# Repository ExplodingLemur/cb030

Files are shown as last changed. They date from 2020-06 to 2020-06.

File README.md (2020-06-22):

# cb030
4-layer redesign of the [CB030](https://www.retrobrewcomputers.org/doku.php?id=builderpages:plasmo:cb030) homebrew computer by plasmo on retrobrewcomputers.org.

Specifically based on the [16-bit CF interface variant rev1](https://www.retrobrewcomputers.org/doku.php?id=builderpages:plasmo:cb030:cb030_rev1:16-bit_cf_upgrade)

Requires [these KiCAD library files](https://github.com/ExplodingLemur/kicad_libs)

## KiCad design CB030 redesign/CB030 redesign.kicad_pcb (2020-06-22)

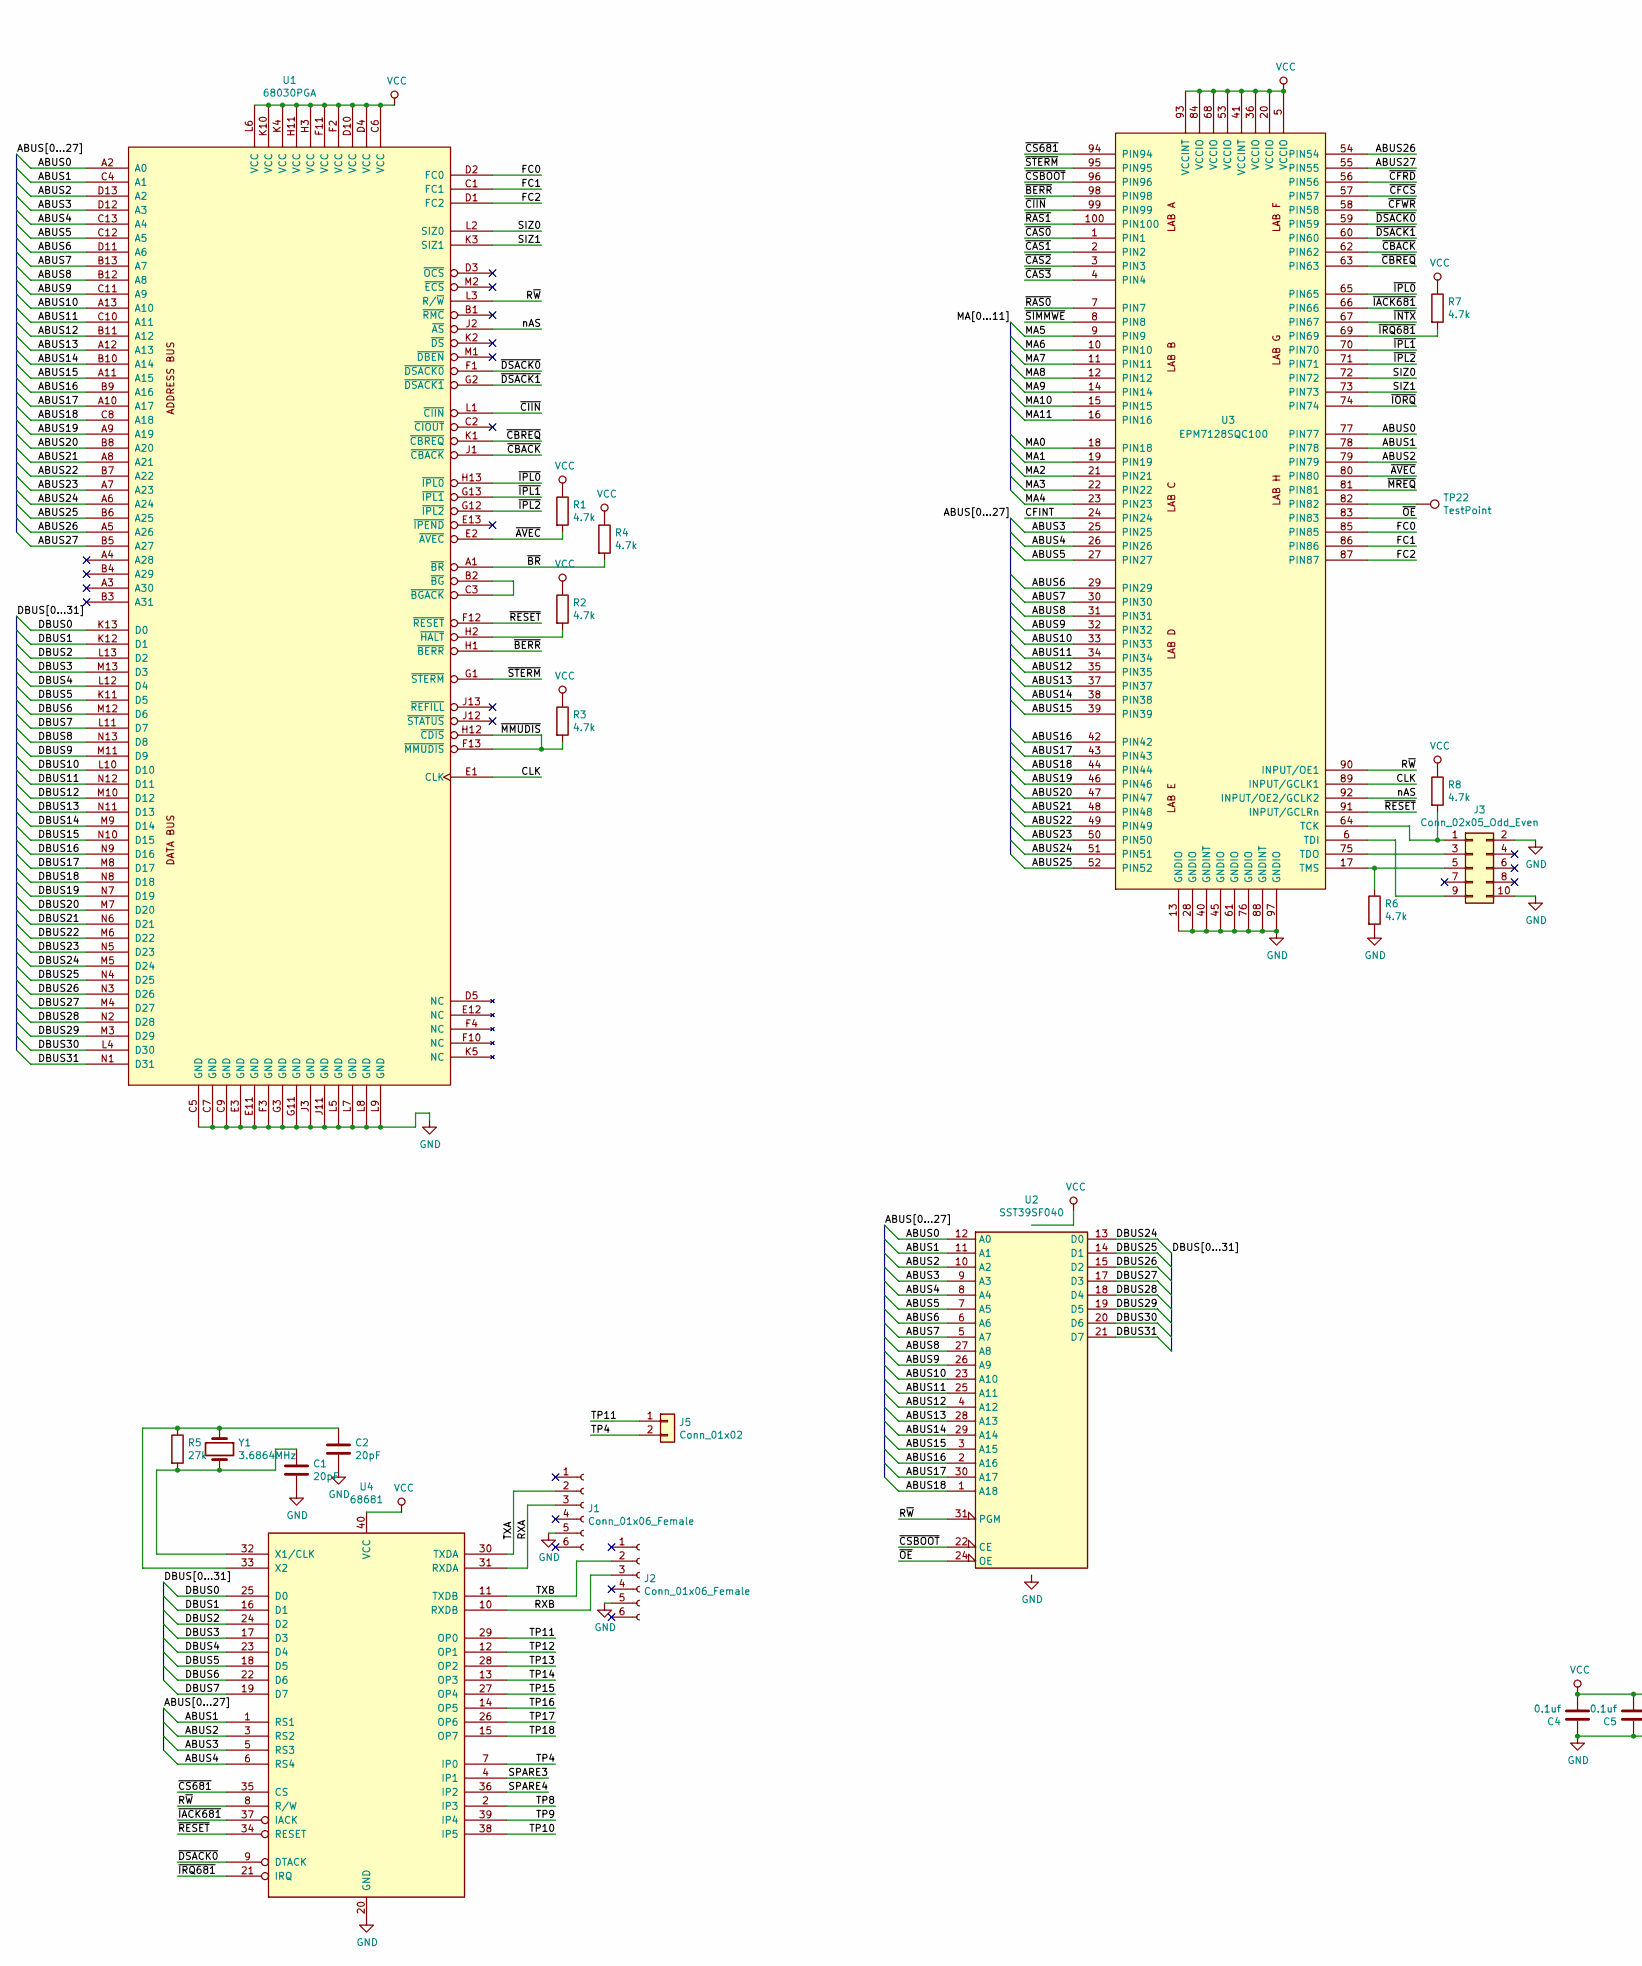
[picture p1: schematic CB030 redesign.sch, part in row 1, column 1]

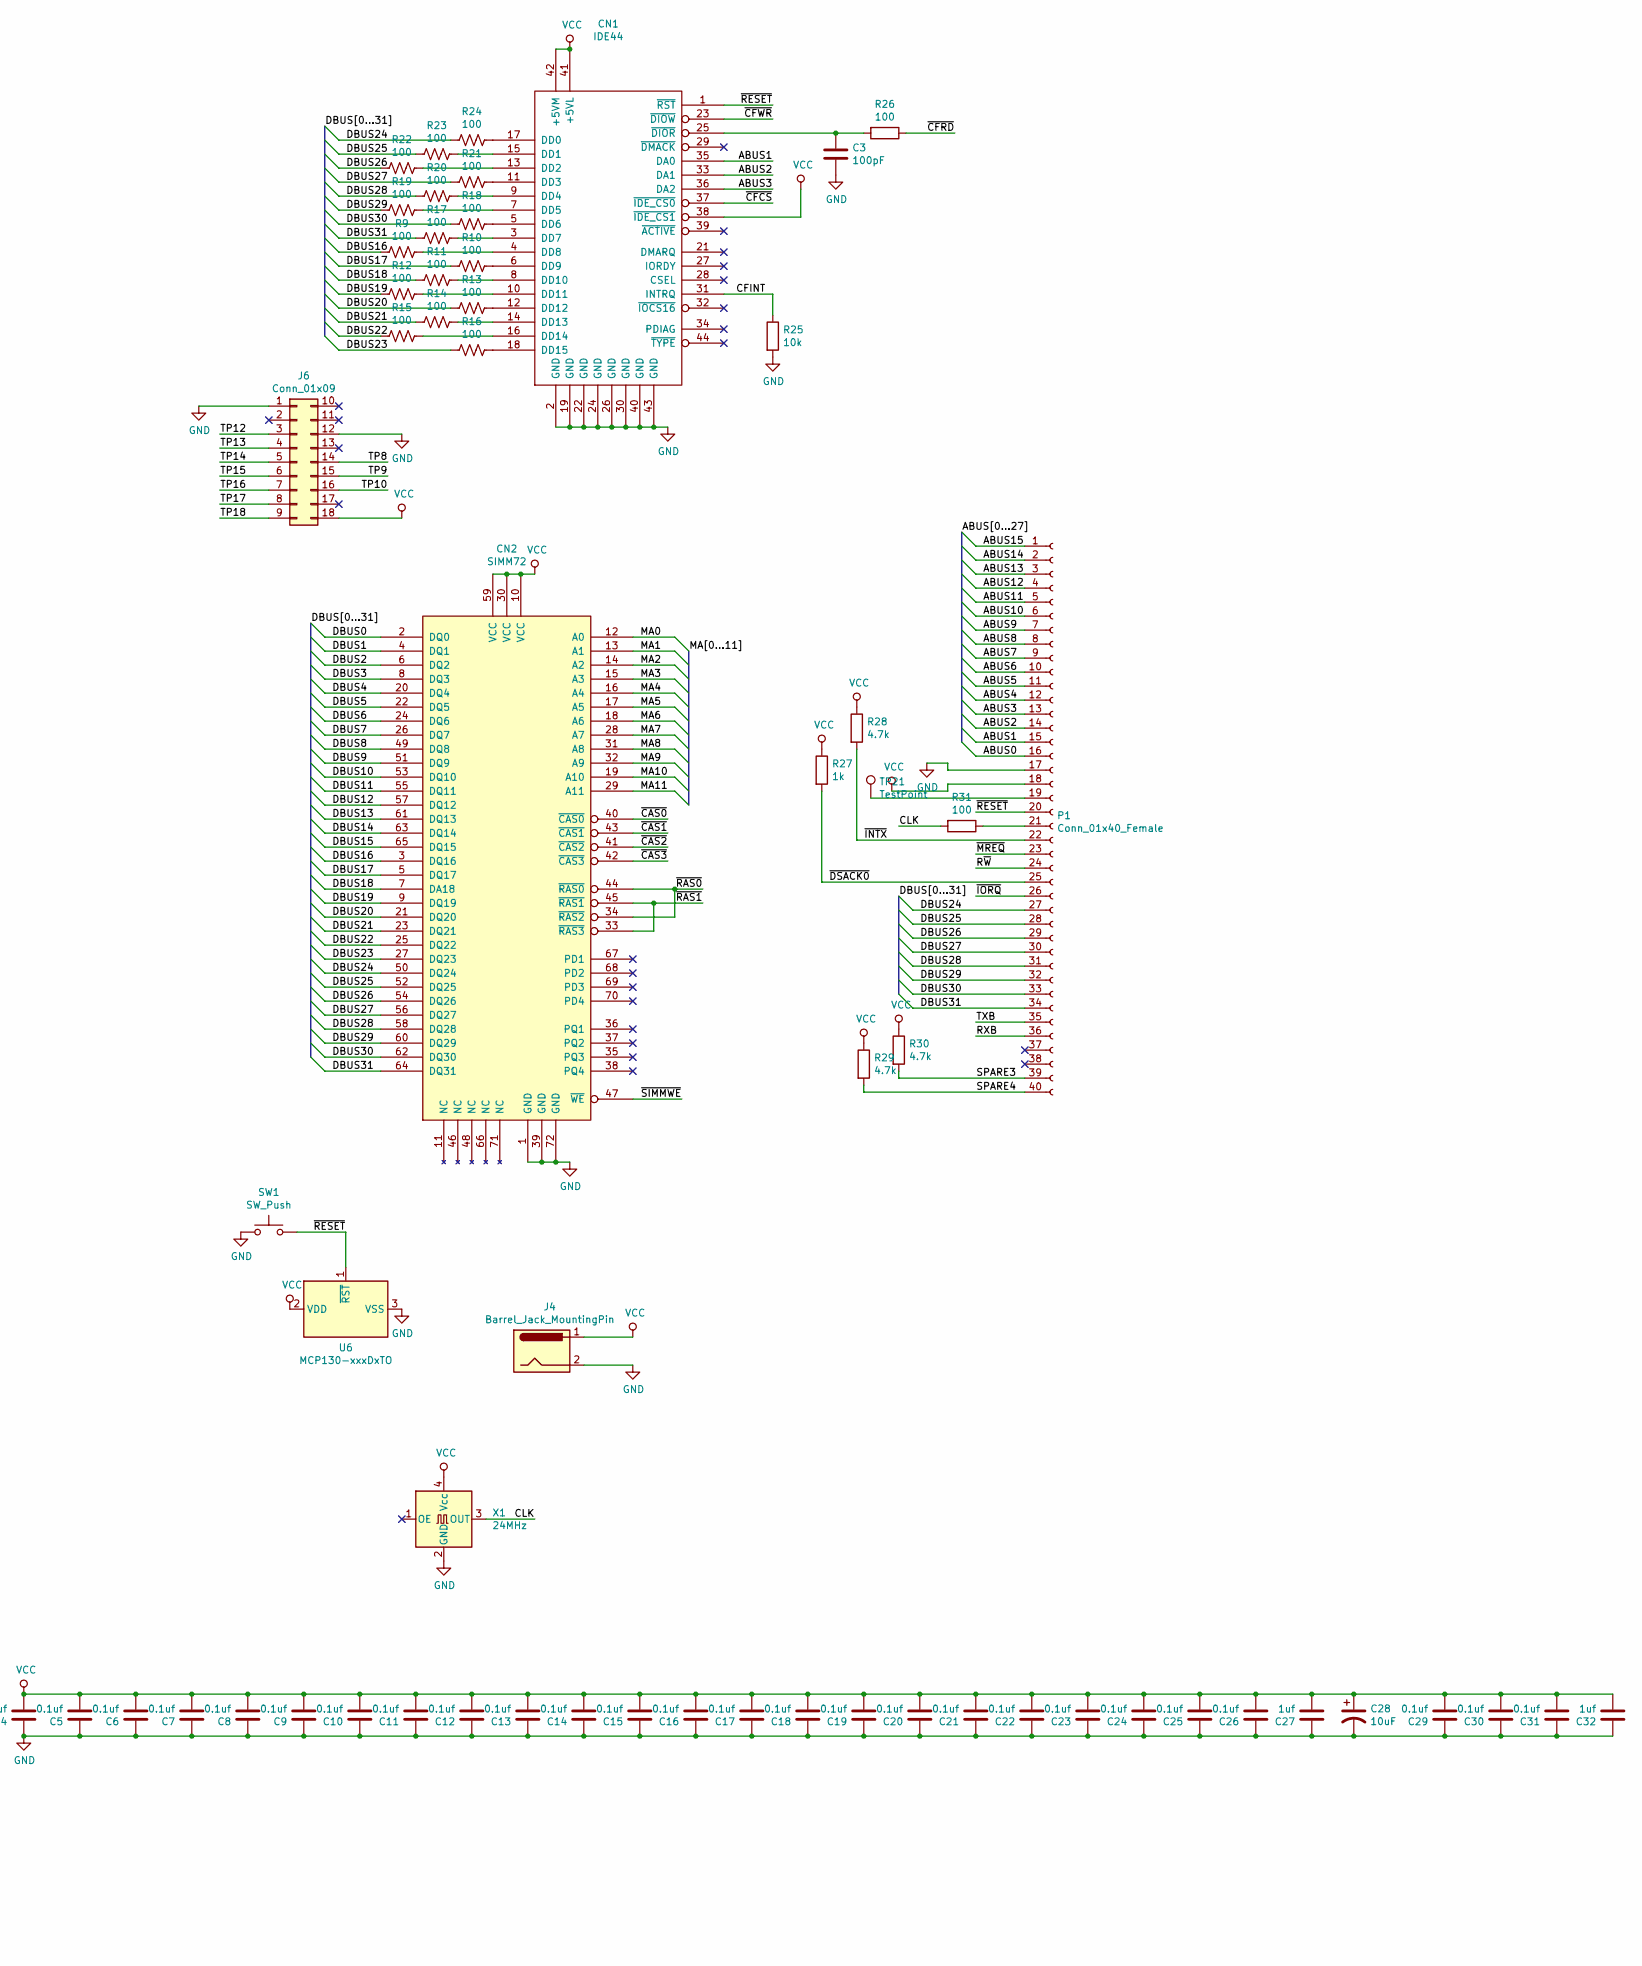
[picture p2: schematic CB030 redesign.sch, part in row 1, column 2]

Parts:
C1, C2: 20pF; C_0805_2012Metric_Pad1.15x1.40mm_HandSolder
C3: 100pF; C_0805_2012Metric_Pad1.15x1.40mm_HandSolder
C4, C5, C6, C7, C8, C9, C10, C11, C12, C13, C14, C15, C16, C17, C18, C19, C20, C21, C22, C23, C24, C25, C26, C29, C30, C31: 0.1uf; C_0805_2012Metric_Pad1.15x1.40mm_HandSolder
C27, C32: 1uf; C_0805_2012Metric_Pad1.15x1.40mm_HandSolder
C28: 10uF; CP_Elec_4x5.8
CN1: IDE44; PinHeader_2x22_P2.00mm_Vertical
CN2: SIMM72; SIMM 72POS LEFT
J1: Conn_01x06_Female; PinSocket_1x06_P2.54mm_Vertical
J2: Conn_01x06_Female; PinSocket_1x06_P2.54mm_Horizontal
J3: Conn_02x05_Odd_Even; PinHeader_2x05_P2.54mm_Vertical
J4: Barrel_Jack_MountingPin; BarrelJack_Horizontal
J5: Conn_01x02; PinHeader_1x02_P2.54mm_Vertical
J6: Conn_01x09; PinHeader_2x09_P2.54mm_Vertical
P1: Conn_01x40_Female; PinSocket_1x40_P2.54mm_Vertical
R1, R2, R3, R4, R6, R7, R8, R28, R29, R30: 4.7k; R_0805_2012Metric_Pad1.15x1.40mm_HandSolder
R5: 27k; R_0805_2012Metric_Pad1.15x1.40mm_HandSolder
R9, R10, R11, R12, R13, R14, R15, R16, R17, R18, R19, R20, R21, R22, R23, R24, R26, R31: 100; R_0805_2012Metric_Pad1.15x1.40mm_HandSolder
R25: 10k; R_0805_2012Metric_Pad1.15x1.40mm_HandSolder
R27: 1k; R_0805_2012Metric_Pad1.15x1.40mm_HandSolder
SW1: SW_Push; SW_PUSH_6mm
TP21, TP22: TestPoint; TestPoint_THTPad_D1.5mm_Drill0.7mm
U1: 68030PGA; MC68030-RC
U2: SST39SF040; DIP-32_W15.24mm_Socket
U3: EPM7128SQC100; PQFP-100_14x20mm_P0.65mm
U4: 68681; DIP-40_W15.24mm_Socket
U6: MCP130-xxxDxTO; TO-92_Inline
X1: 24MHz; Oscillator_SMD_SeikoEpson_SG8002CA-4Pin_7.0x5.0mm_HandSolde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; Part SG7050CCN 24.000000M-HJGA3
Y1: 3.6864MHz; Crystal_SMD_HC49-SD_HandSoldering; Part ABLS-3.6864MHZ-20-B-3-H-T

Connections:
/ABUS0: P1.16, U1.A2 (A0), U2.12 (A0), U3.77 (PIN77)
/ABUS1: CN1.35 (DA0), P1.15, U1.C4 (A1), U2.11 (A1), U3.78 (PIN78), U4.1 (RS1)
/ABUS2: CN1.33 (DA1), P1.14, U1.D13 (A2), U2.10 (A2), U3.79 (PIN79), U4.3 (RS2)
/ABUS3: CN1.36 (DA2), P1.13, U1.D12 (A3), U2.9 (A3), U3.25 (PIN25), U4.5 (RS3)
/ABUS4: P1.12, U1.C13 (A4), U2.8 (A4), U3.26 (PIN26), U4.6 (RS4)
/ABUS5: P1.11, U1.C12 (A5), U2.7 (A5), U3.27 (PIN27)
/ABUS6: P1.10, U1.D11 (A6), U2.6 (A6), U3.29 (PIN29)
/ABUS7: P1.9, U1.B13 (A7), U2.5 (A7), U3.30 (PIN30)
/ABUS8: P1.8, U1.B12 (A8), U2.27 (A8), U3.31 (PIN31)
/ABUS9: P1.7, U1.C11 (A9), U2.26 (A9), U3.32 (PIN32)
/ABUS10: P1.6, U1.A13 (A10), U2.23 (A10), U3.33 (PIN33)
/ABUS11: P1.5, U1.C10 (A11), U2.25 (A11), U3.34 (PIN34)
/ABUS12: P1.4, U1.B11 (A12), U2.4 (A12), U3.35 (PIN35)
/ABUS13: P1.3, U1.A12 (A13), U2.28 (A13), U3.37 (PIN37)
/ABUS14: P1.2, U1.B10 (A14), U2.29 (A14), U3.38 (PIN38)
/ABUS15: P1.1, U1.A11 (A15), U2.3 (A15), U3.39 (PIN39)
/ABUS16: U1.B9 (A16), U2.2 (A16), U3.42 (PIN42)
/ABUS17: U1.A10 (A17), U2.30 (A17), U3.43 (PIN43)
/ABUS18: U1.C8 (A18), U2.1 (A18), U3.44 (PIN44)
/ABUS19: U1.A9 (A19), U3.46 (PIN46)
/ABUS20: U1.B8 (A20), U3.47 (PIN47)
/ABUS21: U1.A8 (A21), U3.48 (PIN48)
/ABUS22: U1.B7 (A22), U3.49 (PIN49)
/ABUS23: U1.A7 (A23), U3.50 (PIN50)
/ABUS24: U1.A6 (A24), U3.51 (PIN51)
/ABUS25: U1.B6 (A25), U3.52 (PIN52)
/ABUS26: U1.A5 (A26), U3.54 (PIN54)
/ABUS27: U1.B5 (A27), U3.55 (PIN55)
/CFINT: CN1.31 (INTRQ), R25.1, U3.24 (PIN24)
/CLK: R31.2, U1.E1 (CLK), U3.89 (INPUT/GCLK1), X1.3 (OUT)
/DBUS0: CN2.2 (DQ0), U1.K13 (D0), U4.25 (D0)
/DBUS1: CN2.4 (DQ1), U1.K12 (D1), U4.16 (D1)
/DBUS2: CN2.6 (DQ2), U1.L13 (D2), U4.24 (D2)
/DBUS3: CN2.8 (DQ3), U1.M13 (D3), U4.17 (D3)
/DBUS4: CN2.20 (DQ4), U1.L12 (D4), U4.23 (D4)
/DBUS5: CN2.22 (DQ5), U1.K11 (D5), U4.18 (D5)
/DBUS6: CN2.24 (DQ6), U1.M12 (D6), U4.22 (D6)
/DBUS7: CN2.26 (DQ7), U1.L11 (D7), U4.19 (D7)
/DBUS8: CN2.49 (DQ8), U1.N13 (D8)
/DBUS9: CN2.51 (DQ9), U1.M11 (D9)
/DBUS10: CN2.53 (DQ10), U1.L10 (D10)
/DBUS11: CN2.55 (DQ11), U1.N12 (D11)
/DBUS12: CN2.57 (DQ12), U1.M10 (D12)
/DBUS13: CN2.61 (DQ13), U1.N11 (D13)
/DBUS14: CN2.63 (DQ14), U1.M9 (D14)
/DBUS15: CN2.65 (DQ15), U1.N10 (D15)
/DBUS16: CN2.3 (DQ16), R9.2, U1.N9 (D16)
/DBUS17: CN2.5 (DQ17), R10.2, U1.M8 (D17)
/DBUS18: CN2.7 (DA18), R11.2, U1.N8 (D18)
/DBUS19: CN2.9 (DQ19), R12.2, U1.N7 (D19)
/DBUS20: CN2.21 (DQ20), R13.2, U1.M7 (D20)
/DBUS21: CN2.23 (DQ21), R14.2, U1.N6 (D21)
/DBUS22: CN2.25 (DQ22), R15.2, U1.M6 (D22)
/DBUS23: CN2.27 (DQ23), R16.2, U1.N5 (D23)
/DBUS24: CN2.50 (DQ24), P1.27, R24.2, U1.M5 (D24), U2.13 (D0)
/DBUS25: CN2.52 (DQ25), P1.28, R23.2, U1.N4 (D25), U2.14 (D1)
/DBUS26: CN2.54 (DQ26), P1.29, R22.2, U1.N3 (D26), U2.15 (D2)
/DBUS27: CN2.56 (DQ27), P1.30, R21.2, U1.M4 (D27), U2.17 (D3)
/DBUS28: CN2.58 (DQ28), P1.31, R20.2, U1.N2 (D28), U2.18 (D4)
/DBUS29: CN2.60 (DQ29), P1.32, R19.2, U1.M3 (D29), U2.19 (D5)
/DBUS30: CN2.62 (DQ30), P1.33, R18.2, U1.L4 (D30), U2.20 (D6)
/DBUS31: CN2.64 (DQ31), P1.34, R17.2, U1.N1 (D31), U2.21 (D7)
/FC0: U1.D2 (FC0), U3.85 (PIN85)
/FC1: U1.C1 (FC1), U3.86 (PIN86)
/FC2: U1.D1 (FC2), U3.87 (PIN87)
/MA0: CN2.12 (A0), U3.18 (PIN18)
/MA1: CN2.13 (A1), U3.19 (PIN19)
/MA2: CN2.14 (A2), U3.21 (PIN21)
/MA3: CN2.15 (A3), U3.22 (PIN22)
/MA4: CN2.16 (A4), U3.23 (PIN23)
/MA5: CN2.17 (A5), U3.9 (PIN9)
/MA6: CN2.18 (A6), U3.10 (PIN10)
/MA7: CN2.28 (A7), U3.11 (PIN11)
/MA8: CN2.31 (A8), U3.12 (PIN12)
/MA9: CN2.32 (A9), U3.14 (PIN14)
/MA10: CN2.19 (A10), U3.15 (PIN15)
/MA11: CN2.29 (A11), U3.16 (PIN16)
/RXA: J1.3, U4.31 (RXDA)
/RXB: J2.3, P1.36, U4.10 (RXDB)
/R~W: P1.24, U1.L3 (R/~W), U2.31 (PGM), U3.90 (INPUT/OE1), U4.8 (R/W)
/SIZ0: U1.L2 (SIZ0), U3.72 (PIN72)
/SIZ1: U1.K3 (SIZ1), U3.73 (PIN73)
/SPARE3: P1.39, R30.2, U4.4 (IP1)
/SPARE4: P1.40, R29.2, U4.36 (IP2)
/TP4: J5.2, U4.7 (IP0)
/TP8: J6.14, U4.2 (IP3)
/TP9: J6.15, U4.39 (IP4)
/TP10: J6.16, U4.38 (IP5)
/TP11: J5.1, U4.29 (OP0)
/TP12: J6.3, U4.12 (OP1)
/TP13: J6.4, U4.28 (OP2)
/TP14: J6.5, U4.13 (OP3)
/TP15: J6.6, U4.27 (OP4)
/TP16: J6.7, U4.14 (OP5)
/TP17: J6.8, U4.26 (OP6)
/TP18: J6.9, U4.15 (OP7)
/TXA: J1.2, U4.30 (TXDA)
/TXB: J2.2, P1.35, U4.11 (TXDB)
/nAS: U1.J2 (~AS), U3.92 (INPUT/OE2/GCLK2)
/~AVEC: R1.2, U1.E2 (~AVEC), U3.80 (PIN80)
/~BERR: U1.H1 (~BERR), U3.98 (PIN98)
/~BR: R4.2, U1.A1 (~BR)
/~CAS0: CN2.40 (~CAS0), U3.1 (PIN1)
/~CAS1: CN2.43 (~CAS1), U3.2 (PIN2)
/~CAS2: CN2.41 (~CAS2), U3.3 (PIN3)
/~CAS3: CN2.42 (~CAS3), U3.4 (PIN4)
/~CBACK: U1.J1 (~CBACK), U3.62 (PIN62)
/~CBREQ: U1.K1 (~CBREQ), U3.63 (PIN63)
/~CFCS: CN1.37 (~IDE_CS0), U3.57 (PIN57)
/~CFRD: R26.1, U3.56 (PIN56)
/~CFWR: CN1.23 (~DIOW), U3.58 (PIN58)
/~CIIN: U1.L1 (~CIIN), U3.99 (PIN99)
/~CS681: U3.94 (PIN94), U4.35 (CS)
/~CSBOOT: U2.22 (CE), U3.96 (PIN96)
/~DSACK0: P1.25, R27.2, U1.F1 (~DSACK0), U3.59 (PIN59), U4.9 (DTACK)
/~DSACK1: U1.G2 (~DSACK1), U3.60 (PIN60)
/~IACK681: U3.66 (PIN66), U4.37 (IACK)
/~INTX: P1.22, R28.2, U3.67 (PIN67)
/~IORQ: P1.26, U3.74 (PIN74)
/~IPL0: U1.H13 (~IPL0), U3.65 (PIN65)
/~IPL1: U1.G13 (~IPL1), U3.70 (PIN70)
/~IPL2: U1.G12 (~IPL2), U3.71 (PIN71)
/~IRQ681: R7.2, U3.69 (PIN69), U4.21 (IRQ)
/~MMUDIS: R3.2, U1.F13 (~MMUDIS), U1.H12 (~CDIS)
/~MREQ: P1.23, U3.81 (PIN81)
/~OE: U2.24 (OE), U3.83 (PIN83)
/~RAS0: CN2.34 (~RAS2), CN2.44 (~RAS0), U3.7 (PIN7)
/~RAS1: CN2.33 (~RAS3), CN2.45 (~RAS1), U3.100 (PIN100)
/~RESET: CN1.1 (~RST), P1.20, SW1.2, U1.F12 (~RESET), U3.91 (INPUT/GCLRn), U4.34 (RESET), U6.1 (~RST)
/~SIMMWE: CN2.47 (~WE), U3.8 (PIN8)
/~STERM: U1.G1 (~STERM), U3.95 (PIN95)
GND: C1.2, C2.2, C3.2, C4.1, C5.1, C6.1, C7.1, C8.1, C9.1, C10.1, C11.1, C12.1, C13.1, C14.1, C15.1, C16.1, C17.1, C18.1, C19.1, C20.1, C21.1, C22.1, C23.1, C24.1, C25.1, C26.1, C27.1, C28.2, C29.1, C30.1, C31.1, C32.1, CN1.2 (GND), CN1.19 (GND), CN1.22 (GND), CN1.24 (GND), CN1.26 (GND), CN1.30 (GND), CN1.40 (GND), CN1.43 (GND), CN2.1 (GND), CN2.39 (GND), CN2.72 (GND), J1.5, J2.5, J3.2, J3.10, J4.2, J6.1, J6.12, P1.17, R6.2, R25.2, SW1.1, U1.C5 (GND), U1.C7 (GND), U1.C9 (GND), U1.E3 (GND), U1.E11 (GND), U1.F3 (GND), U1.G3 (GND), U1.G11 (GND), U1.J3 (GND), U1.J11 (GND), U1.L5 (GND), U1.L7 (GND), U1.L8 (GND), U1.L9 (GND), U2.16 (GND), U3.13 (GNDIO), U3.28 (GNDIO), U3.40 (GNDINT), U3.45 (GNDIO), U3.61 (GNDIO), U3.76 (GNDIO), U3.88 (GNDINT), U3.97 (GNDIO), U4.20 (GND), U6.3 (VSS), X1.2 (GND)
unnamed: C1.1, R5.2, U4.32 (X1/CLK), Y1.2
unnamed: C2.1, R5.1, U4.33 (X2), Y1.1
unnamed: C3.1, CN1.25 (~DIOR), R26.2
unnamed: CN1.3 (DD7), R17.1
unnamed: CN1.4 (DD8), R9.1
unnamed: CN1.5 (DD6), R18.1
unnamed: CN1.6 (DD9), R10.1
unnamed: CN1.7 (DD5), R19.1
unnamed: CN1.8 (DD10), R11.1
unnamed: CN1.9 (DD4), R20.1
unnamed: CN1.10 (DD11), R12.1
unnamed: CN1.11 (DD3), R21.1
unnamed: CN1.12 (DD12), R13.1
unnamed: CN1.13 (DD2), R22.1
unnamed: CN1.14 (DD13), R14.1
unnamed: CN1.15 (DD1), R23.1
unnamed: CN1.16 (DD14), R15.1
unnamed: CN1.17 (DD0), R24.1
unnamed: CN1.18 (DD15), R16.1
unnamed: J3.1, R8.2, U3.64 (TCK)
unnamed: J3.3, U3.75 (TDO)
unnamed: J3.5, R6.1, U3.17 (TMS)
unnamed: J3.9, U3.6 (TDI)
unnamed: P1.19, TP21.1
unnamed: P1.21, R31.1
unnamed: R2.2, U1.H2 (~HALT)
unnamed: TP22.1, U3.82 (PIN82)
unnamed: U1.B2 (~BG), U1.C3 (~BGACK)
VCC: C4.2, C5.2, C6.2, C7.2, C8.2, C9.2, C10.2, C11.2, C12.2, C13.2, C14.2, C15.2, C16.2, C17.2, C18.2, C19.2, C20.2, C21.2, C22.2, C23.2, C24.2, C25.2, C26.2, C27.2, C28.1, C29.2, C30.2, C31.2, C32.2, CN1.38 (~IDE_CS1), CN1.41 (+5VL), CN1.42 (+5VM), CN2.10 (VCC), CN2.30 (VCC), CN2.59 (VCC), J4.1, J6.18, P1.18, R1.1, R2.1, R3.1, R4.1, R7.1, R8.1, R27.1, R28.1, R29.1, R30.1, U1.C6 (VCC), U1.D4 (VCC), U1.D10 (VCC), U1.F2 (VCC), U1.F11 (VCC), U1.H3 (VCC), U1.H11 (VCC), U1.K4 (VCC), U1.K10 (VCC), U1.L6 (VCC), U2.32 (VCC), U3.5 (VCCIO), U3.20 (VCCIO), U3.36 (VCCIO), U3.41 (VCCINT), U3.53 (VCCIO), U3.68 (VCCIO), U3.84 (VCCIO), U3.93 (VCCINT), U4.40 (VCC), U6.2 (VDD), X1.4 (Vcc)

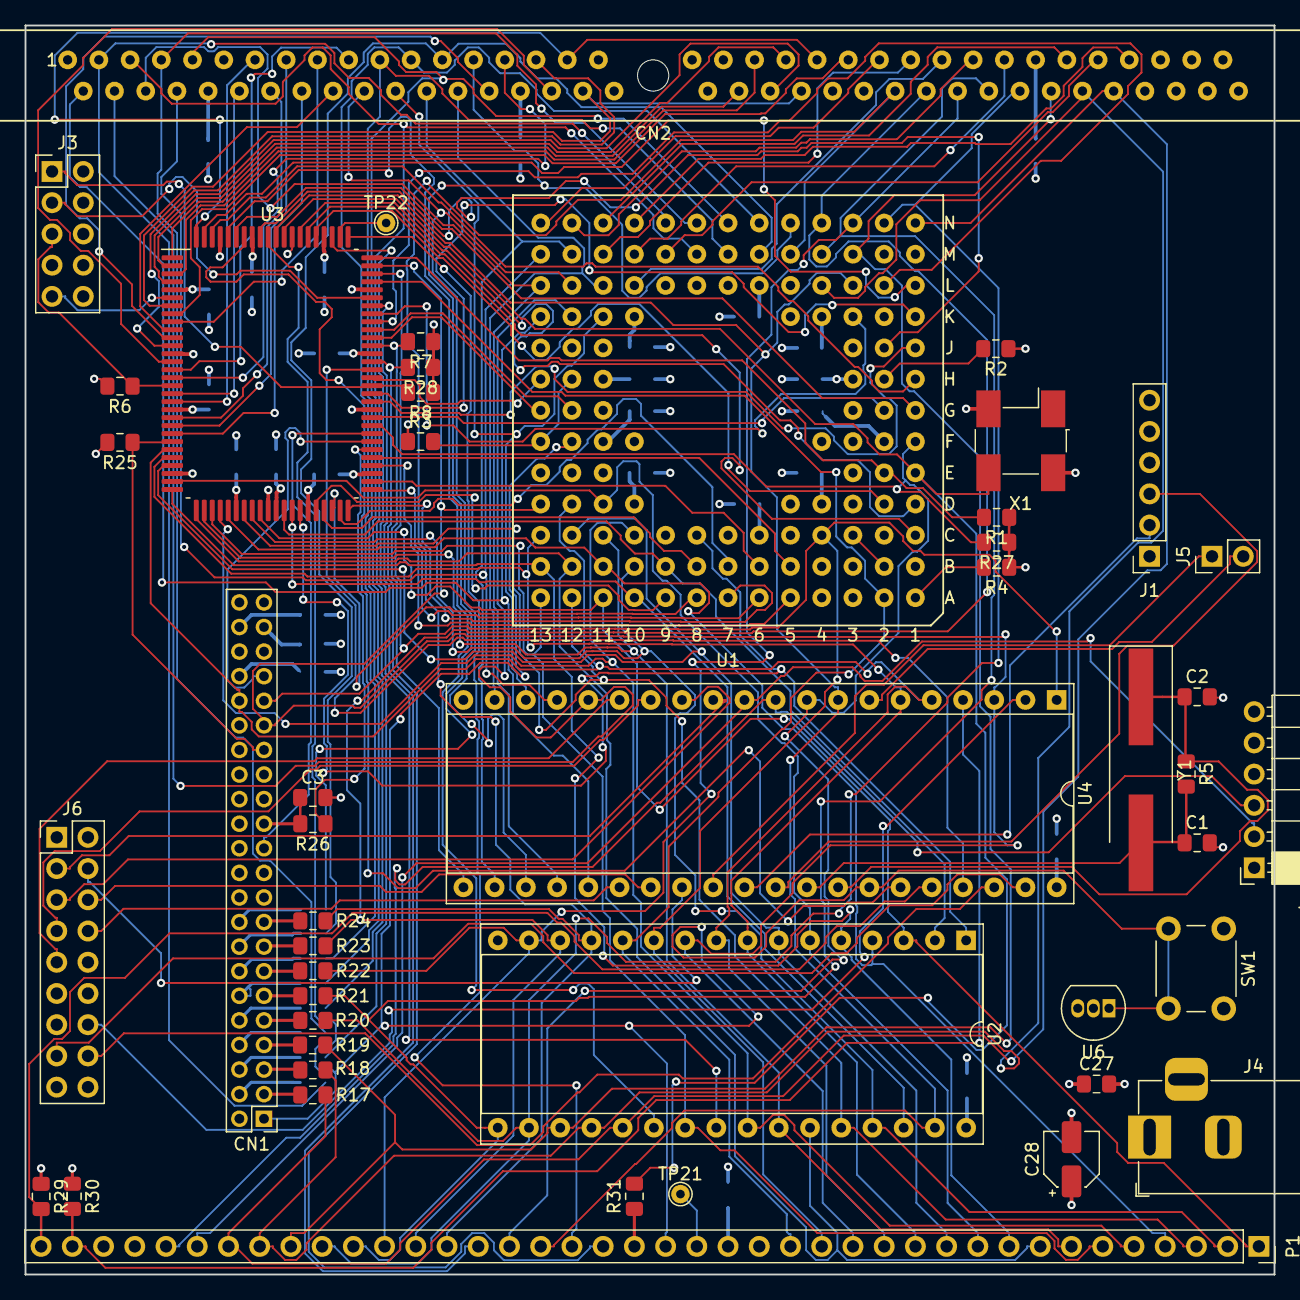
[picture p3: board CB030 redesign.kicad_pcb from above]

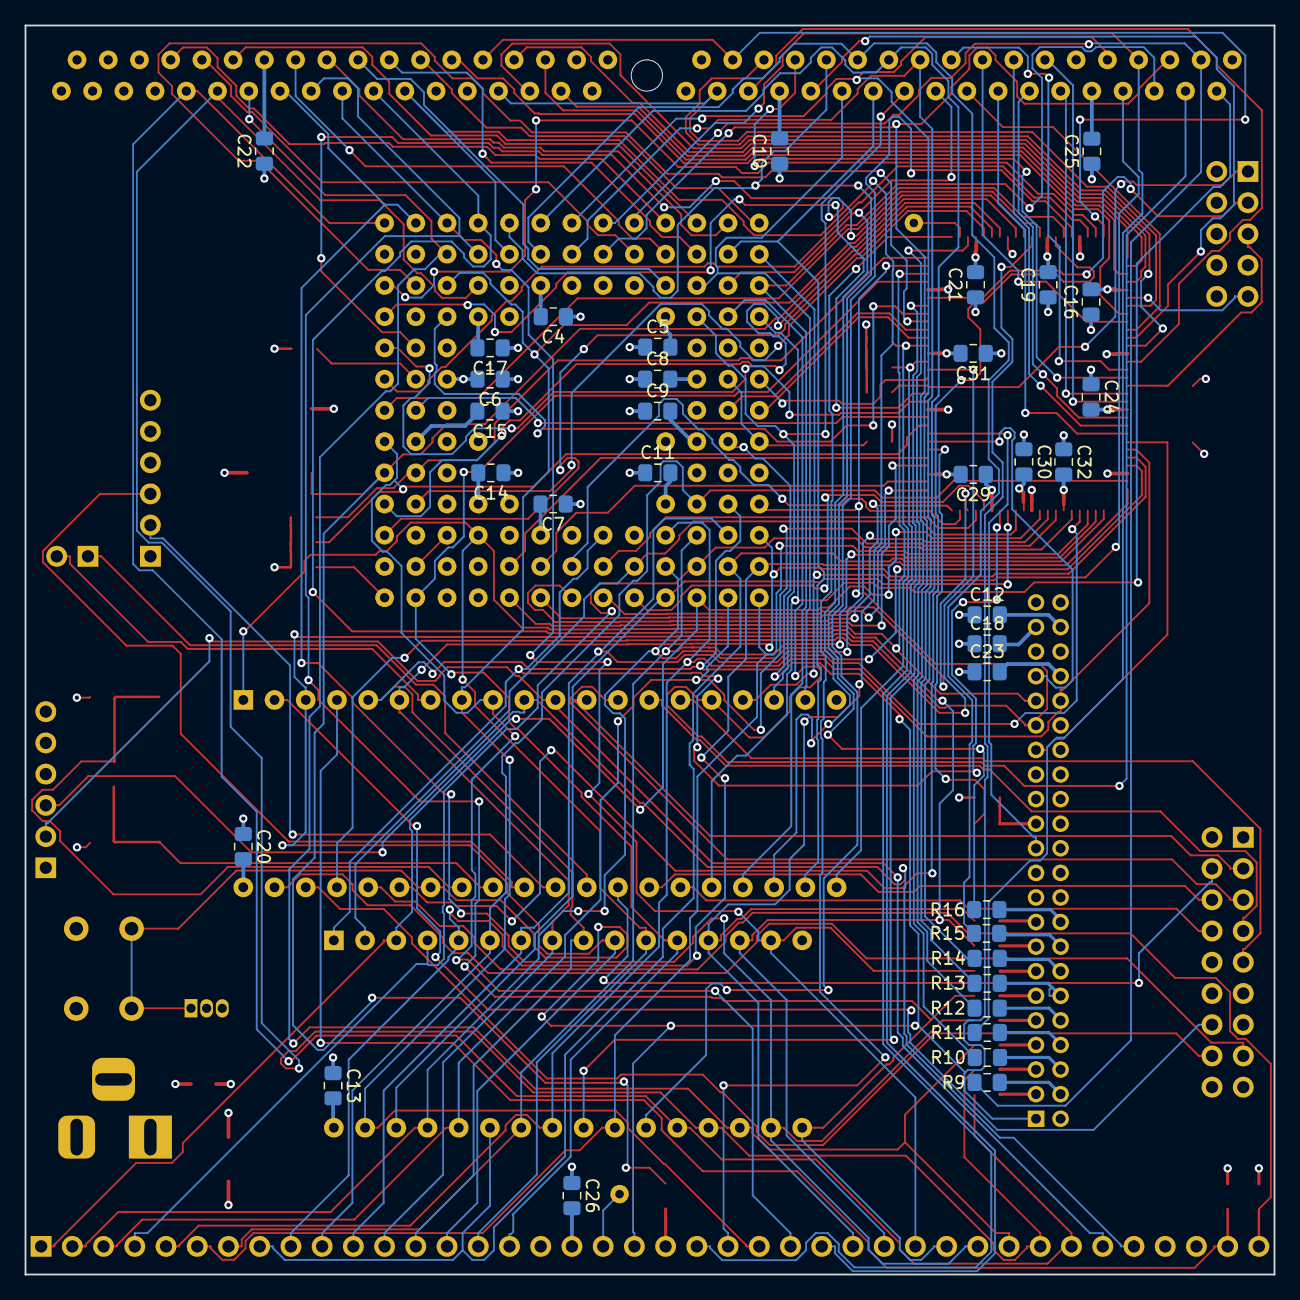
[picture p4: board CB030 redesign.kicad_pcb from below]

Board: 4 copper layers, 101.6 x 101.6 mm, 82 parts (35 on the bottom side), 161 nets.
